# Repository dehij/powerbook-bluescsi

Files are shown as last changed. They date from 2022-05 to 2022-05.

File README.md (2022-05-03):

BlueSCSI PowerBook edition by dehij
v2 version

This BlueSCSI board is designed and tested with Macintosh PowerBooks (tested on 140 and 145B).

Differences with v1:
- uses 1206 SMD termination resistors (18x 220 ohm, 18x 330 ohm)
- uses a different microSD card slot which is easier to find online

Uses the following external footprints:

STM32 BluePill symbol and footprint:
https://github.com/yet-another-average-joe/Kicad-STM32

push-push microSD card footprint by @Joan_Sparky and used with permission. (found in: Other footprints/)

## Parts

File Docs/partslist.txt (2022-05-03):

Needed for 1 unit:

- 1x this PCB
- 1x STM32F103C8T6 BluePill or CH32F103C8T6 BluePill
- 18x SMD 1206 resistor 220 ohm
- 18x SMD 1206 resistor 330 ohm
- 1x 9 pin SD card slot 14x15mm (can't find a part name, it should look like this example: aliexpress.com/item/32802051702.html)
- 1x 2x20 2.0mm pitch 90 degree header (you can also buy a 2x40 90 degree header, you just need to cut it in half)
	it HAS to be 2.0mm pitch!

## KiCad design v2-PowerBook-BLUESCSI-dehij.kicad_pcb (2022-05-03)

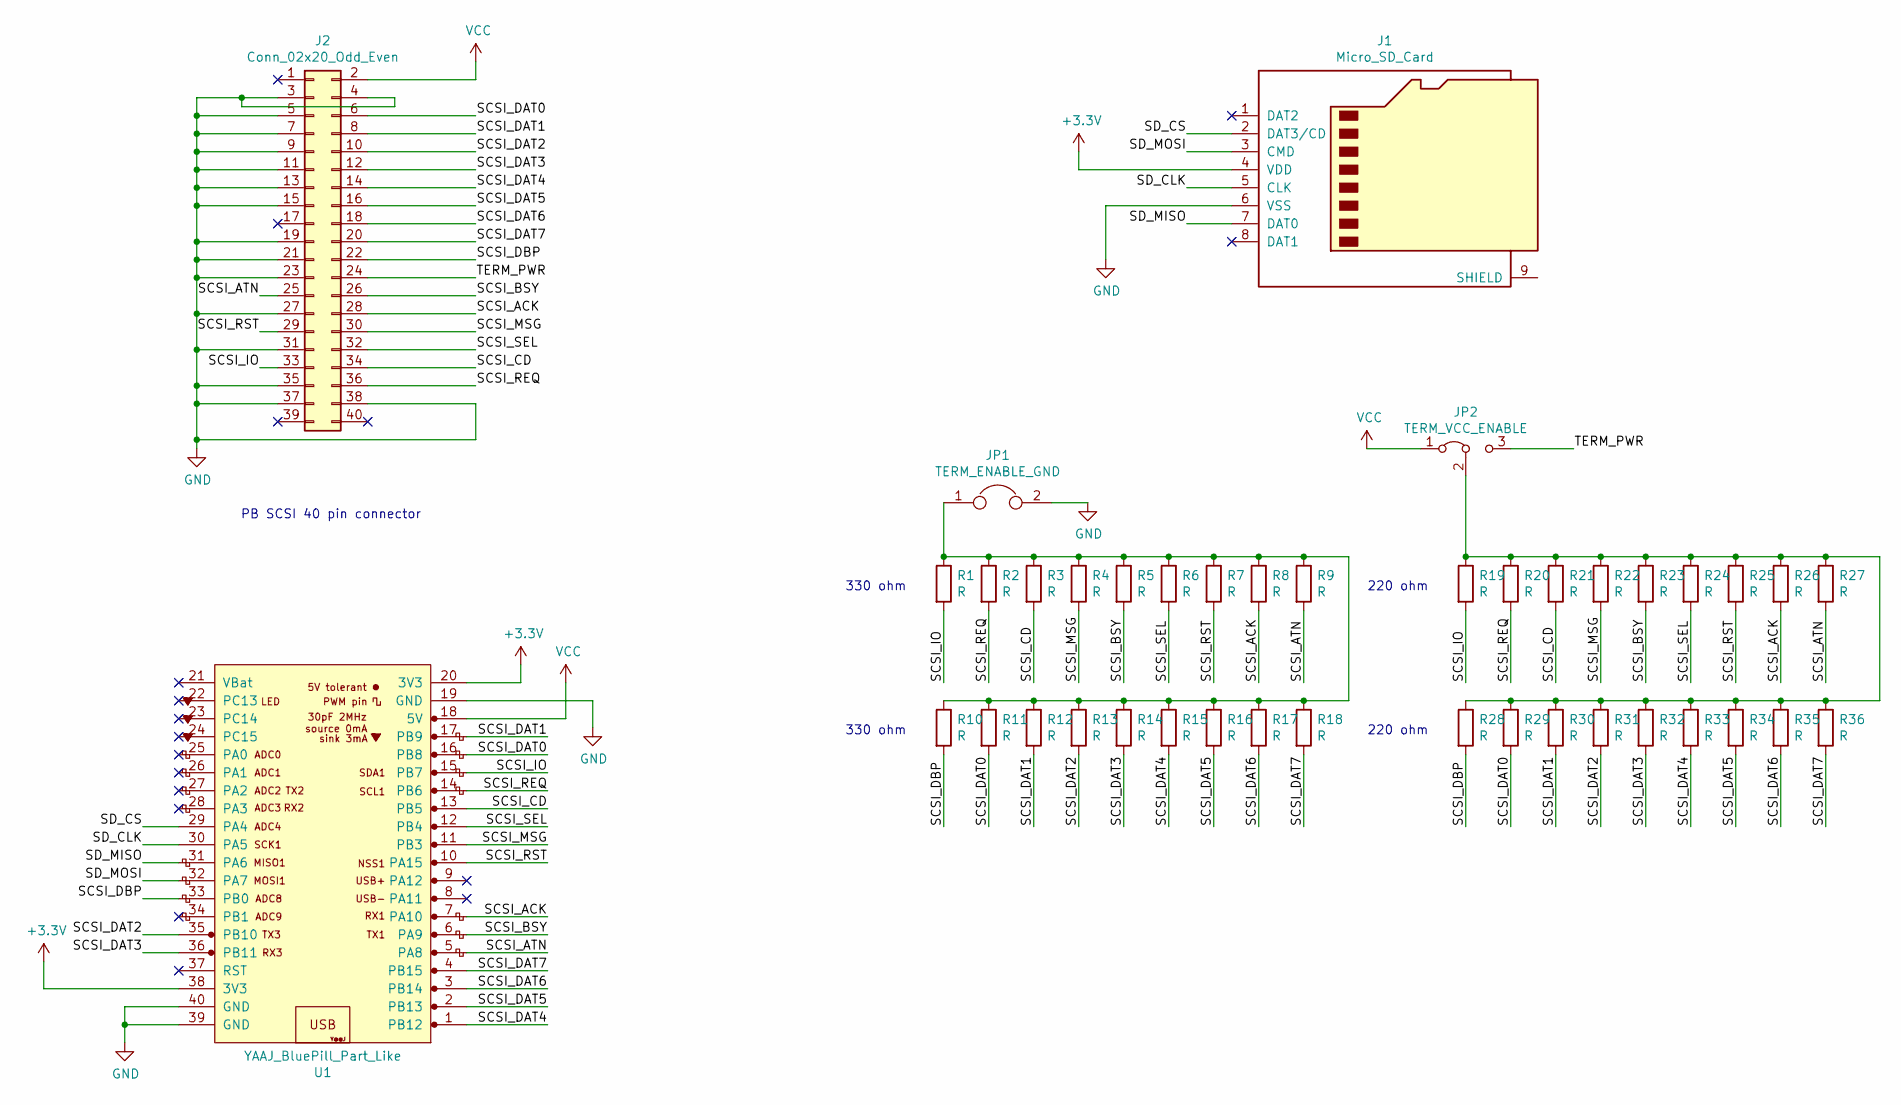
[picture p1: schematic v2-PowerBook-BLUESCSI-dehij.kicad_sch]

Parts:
J1: Micro_SD_Card; Conn_uSDcard
J2: Conn_02x20_Odd_Even; PinSocket_2x20_P2.00mm_Vertical
JP1: TERM_ENABLE_GND; SolderJumper-2_P1.3mm_Bridged_Pad1.0x1.5mm
JP2: TERM_VCC_ENABLE; SolderJumper-3_P1.3mm_Bridged12_Pad1.0x1.5mm_NumberLabels
R1, R2, R3, R4, R5, R6, R7, R8, R9, R10, R11, R12, R13, R14, R15, R16, R17, R18, R19, R20, R21, R22, R23, R24, R25, R26, R27, R28, R29, R30, R31, R32, R33, R34, R35, R36: R; R_1206_3216Metric_Pad1.30x1.75mm_HandSolder
U1: YAAJ_BluePill_Part_Like; YAAJ_BluePill_2

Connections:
+3V3: J1.4 (VDD), U1.20 (3V3), U1.38 (3V3)
/SCSI_ACK: J2.28, R8.2, R26.2, U1.7 (PA10)
/SCSI_ATN: J2.25, R9.2, R27.2, U1.5 (PA8)
/SCSI_BSY: J2.26, R5.2, R23.2, U1.6 (PA9)
/SCSI_CD: J2.34, R3.2, R21.2, U1.13 (PB5)
/SCSI_DAT0: J2.6, R11.2, R29.2, U1.16 (PB8)
/SCSI_DAT1: J2.8, R12.2, R30.2, U1.17 (PB9)
/SCSI_DAT2: J2.10, R13.2, R31.2, U1.35 (PB10)
/SCSI_DAT3: J2.12, R14.2, R32.2, U1.36 (PB11)
/SCSI_DAT4: J2.14, R15.2, R33.2, U1.1 (PB12)
/SCSI_DAT5: J2.16, R16.2, R34.2, U1.2 (PB13)
/SCSI_DAT6: J2.18, R17.2, R35.2, U1.3 (PB14)
/SCSI_DAT7: J2.20, R18.2, R36.2, U1.4 (PB15)
/SCSI_DBP: J2.22, R10.2, R28.2, U1.33 (PB0)
/SCSI_IO: J2.33, R1.2, R19.2, U1.15 (PB7)
/SCSI_MSG: J2.30, R4.2, R22.2, U1.11 (PB3)
/SCSI_REQ: J2.36, R2.2, R20.2, U1.14 (PB6)
/SCSI_RST: J2.29, R7.2, R25.2, U1.10 (PA15)
/SCSI_SEL: J2.32, R6.2, R24.2, U1.12 (PB4)
/SD_CLK: J1.5 (CLK), U1.30 (PA5)
/SD_CS: J1.2 (DAT3/CD), U1.29 (PA4)
/SD_MISO: J1.7 (DAT0), U1.31 (PA6)
/SD_MOSI: J1.3 (CMD), U1.32 (PA7)
/TERM_PWR: J2.24, JP2.3 (B)
GND: J1.6 (VSS), J2.3, J2.4, J2.5, J2.7, J2.9, J2.11, J2.13, J2.15, J2.19, J2.21, J2.23, J2.27, J2.31, J2.35, J2.37, J2.38, JP1.2, U1.19 (GND), U1.39 (GND), U1.40 (GND)
unnamed: JP1.1, R1.1, R2.1, R3.1, R4.1, R5.1, R6.1, R7.1, R8.1, R9.1, R10.1, R11.1, R12.1, R13.1, R14.1, R15.1, R16.1, R17.1, R18.1
unnamed: JP2.2 (C), R19.1, R20.1, R21.1, R22.1, R23.1, R24.1, R25.1, R26.1, R27.1, R28.1, R29.1, R30.1, R31.1, R32.1, R33.1, R34.1, R35.1, R36.1
VCC: J2.2, JP2.1 (A), U1.18 (5V)

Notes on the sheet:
PB SCSI 40 pin connector
330 ohm
220 ohm
220 ohm

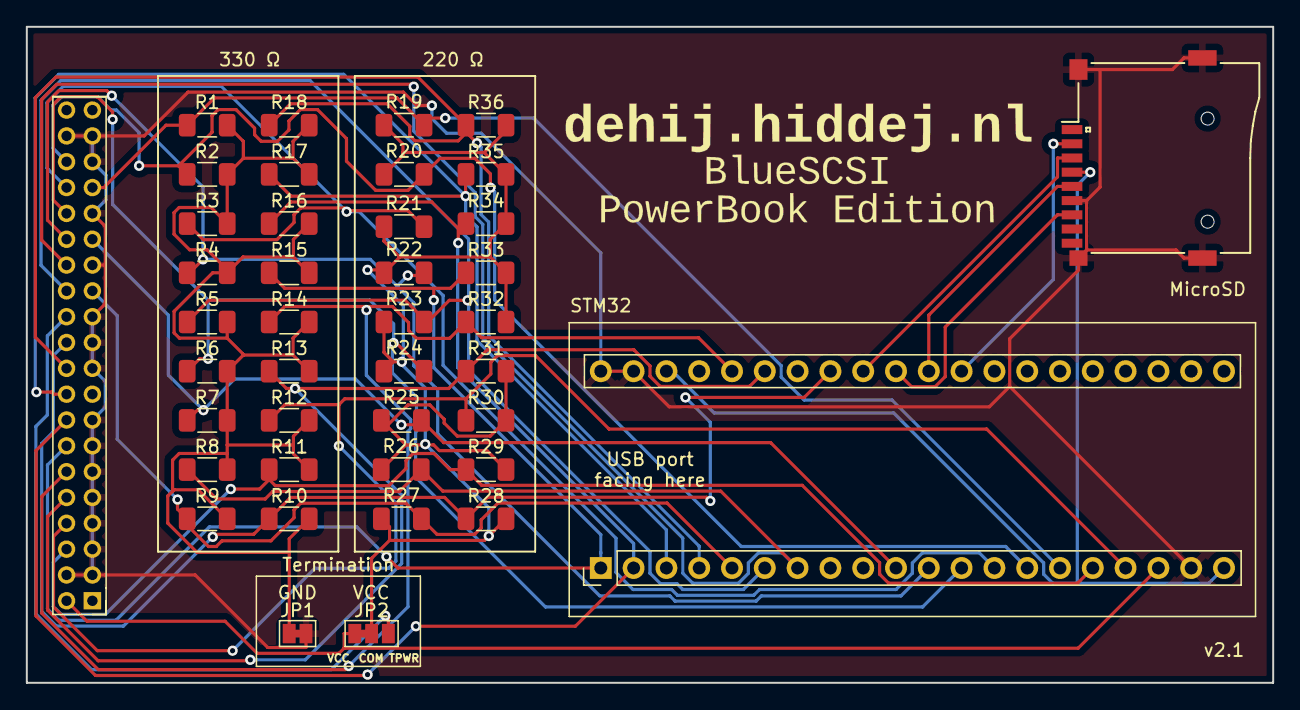
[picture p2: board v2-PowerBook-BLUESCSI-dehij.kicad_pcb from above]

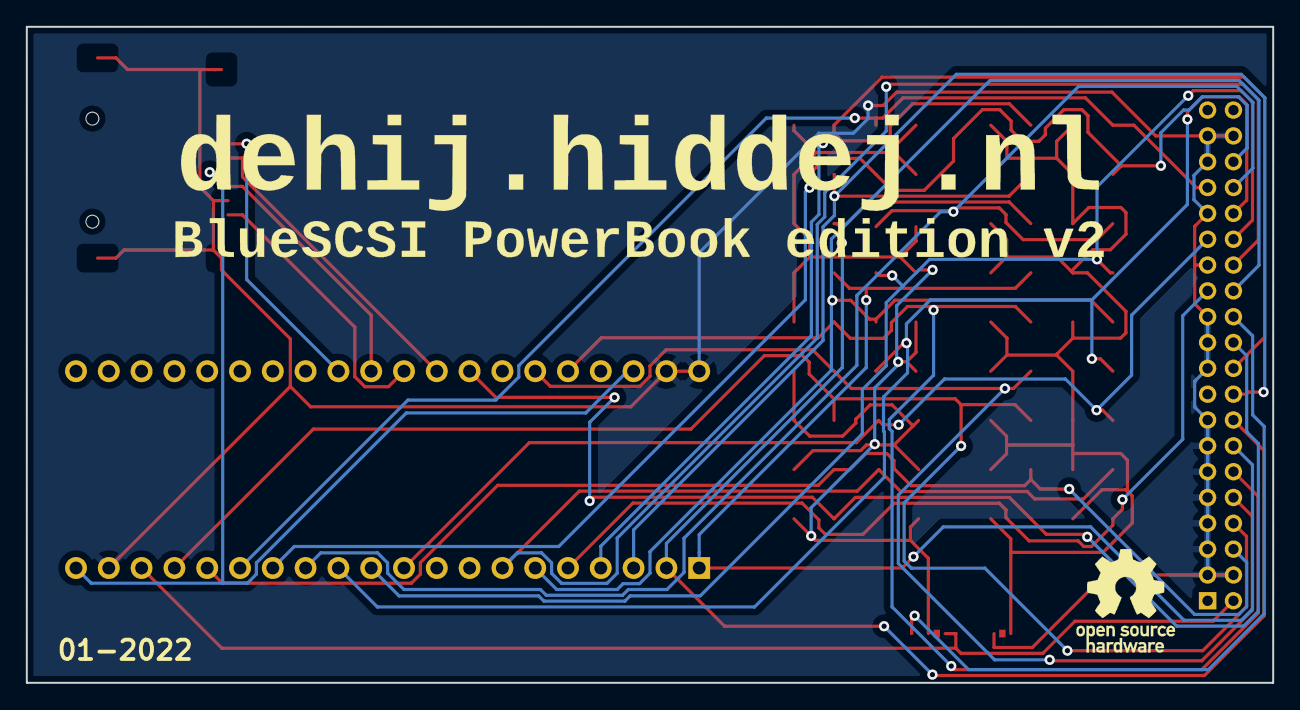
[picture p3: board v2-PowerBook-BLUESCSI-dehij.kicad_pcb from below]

Board: 2 copper layers, 96.5 x 50.8 mm, 43 parts (2 on the bottom side), 28 nets.

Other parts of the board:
G1: LOGO; Backsilkscreen
G2: LOGO; PBlogo2

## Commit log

2021-09-30 Add V1 files
    [bluepill_scsi-B_Cu.gbr, bluepill_scsi-B_Mask.gbr, bluepill_scsi-B_SilkS.gbr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]
2022-05-03 Add V2 files
    Deleted v1 and added v2 board revision.
    [bluepill_scsi-B_Cu.gbr, bluepill_scsi-B_Mask.gbr, bluepill_scsi-B_SilkS.gbr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]
